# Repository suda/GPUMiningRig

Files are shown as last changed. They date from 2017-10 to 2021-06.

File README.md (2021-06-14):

# 6 GPU Mining Rig

<p align="center"><em>
	Read this in other languages: <a href="README.md">English</a>, <a href="README.pt-br.md">Português-Brasil</a>
</em></p>

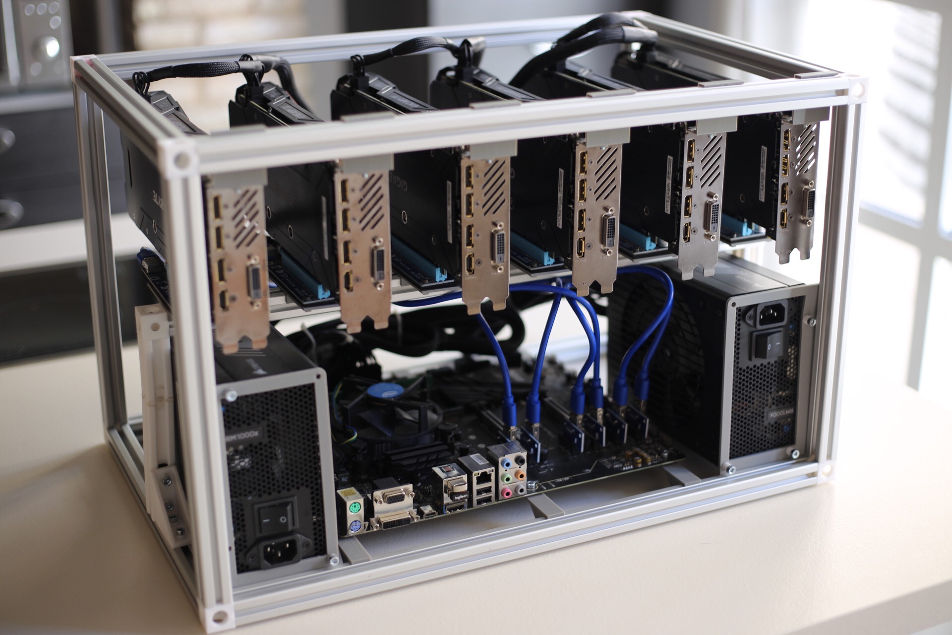
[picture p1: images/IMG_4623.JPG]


## General info

* Dimensions: 540x340x340mm
* Support for two PSUs
* Stackable
* Build cost: ~€60

### 💰 Donations

If you successfully build one I would appreciate some kickback ☺️

* **BTC:** `1K7Uc9MDzokCGEsUxrQQXn59VQ1Q9AWGvZ`
* **BCH:** `1BHM8oACVN6F4xksXAAP3nR9EoAkfd8sGF`
* **ETH:** `0x8CcA7589d8061ad4D3D913412d1EAD71cbEae081`
* **LTC:** `LRJ4Evzmyynp8Uswiy7e2uWhPKBNiSHroq`

## Parts, materials and tools

### Metal
* 5x 2020 500mm profiles
* 8x 2020 300mm profiles
* 2x 2020 150mm profiles
* 16x M3 8mm screws
* 40x M4 8mm screws
* 8x PC case 4mm screws
* 40x M4 nuts
* 28x M6 16mm screws (Make sure to get flat, countersunk screwheads)
* Zip ties

### 3D Printed

* 6x [GPU Bracket Rail](parts/GPUBracketRail.stl)
* 6x [Raiser Rail](parts/RaiserRail.stl)
* [PSU Frame Left](parts/PSUFrameLeft.stl)
* [PSU Frame Right](parts/PSUFrameRight.stl)
* [62mm Mobo Bracket Rail](parts/MoboBracketRail62mm.stl)
* 2x [40mm Mobo Bracket Rail](parts/MoboBracketRail40mm.stl)
* 3x [33mm Mobo Bracket Rail](parts/MoboBracketRail33mm.stl)
* 4x [Right Angle Bracket](parts_others/90_bracket.stl)
* 10x [2020 Corner Connector](parts_others/2020_connect_v2.stl)
* 40x [T Slot nut](parts_others/t_slot_nut_m4.stl)

## Optional
* 4x [Feet_v1](parts/Feet_v1.stl)
* 4x [Rail-Snapper-Insert__MotherBoardv1](parts/Rail-Snapper-Insert__MotherBoardv1.stl)
* 	These can be used to snap the motherboard brackets into place, so you won't need the screws.

### Tools

* Drill
* M6 screw tap
* 3D Printer

## Assembly

**Note:** Any dimensions are measured on the inner parts of the frame.

#### 1. Thread all the profiles
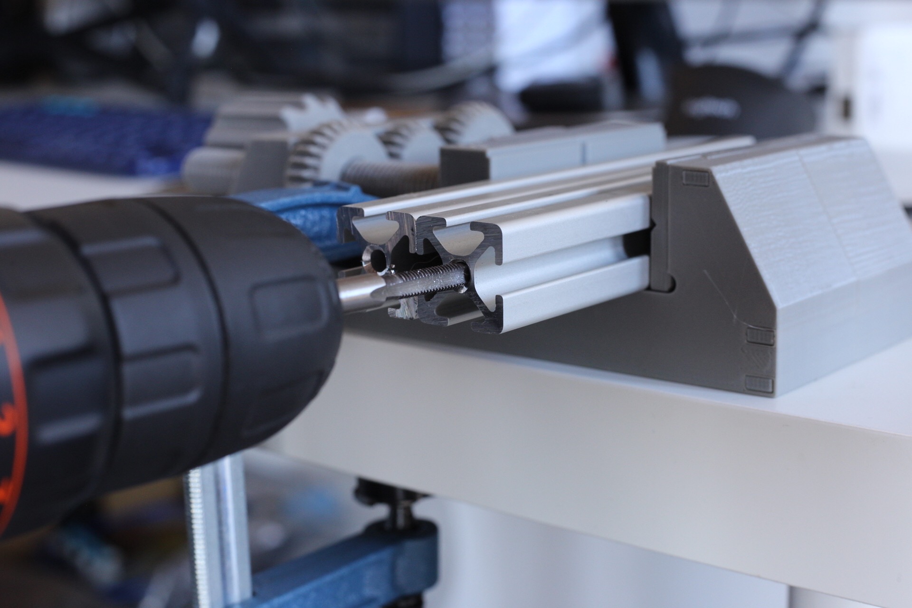
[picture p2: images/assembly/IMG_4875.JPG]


#### 2. Put M4 nuts into all printed T Slot nuts
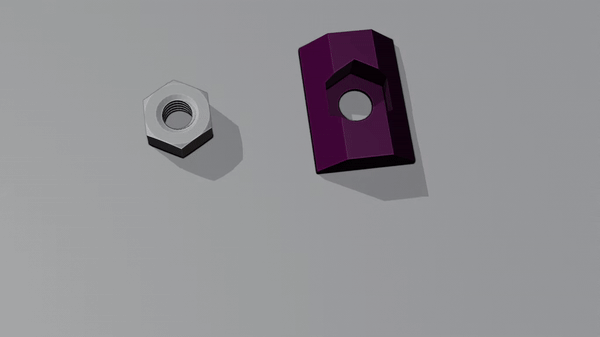
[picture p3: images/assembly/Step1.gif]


#### 3. Place the T Slot nuts in the following profiles:
	* 2x 6 nuts in 500mm
	* 7 nuts in 500mm
	* 3 nuts in 400mm
	* 4x 2 nuts in 300mm

#### 4. Screw the frame together using the M6 screws, 300mm+500mm profiles and the 2020 Corner Connectors

#### 5. Screw the PSU frames to both power supplies
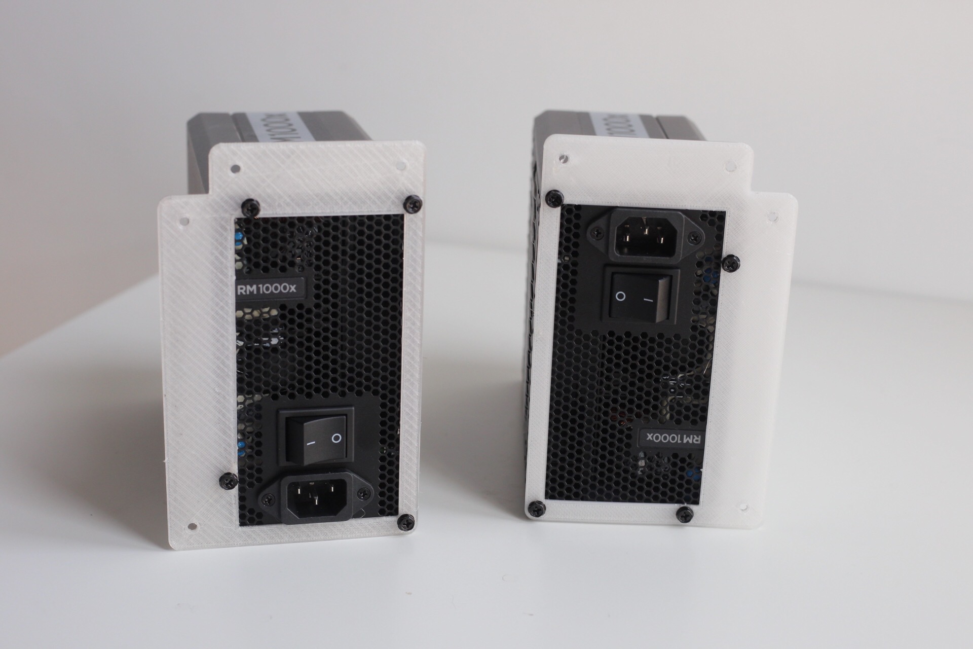
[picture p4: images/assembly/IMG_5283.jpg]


#### 6. Screw the PSU support Right Angle Brackets
**Note:** ~116mm from the back.
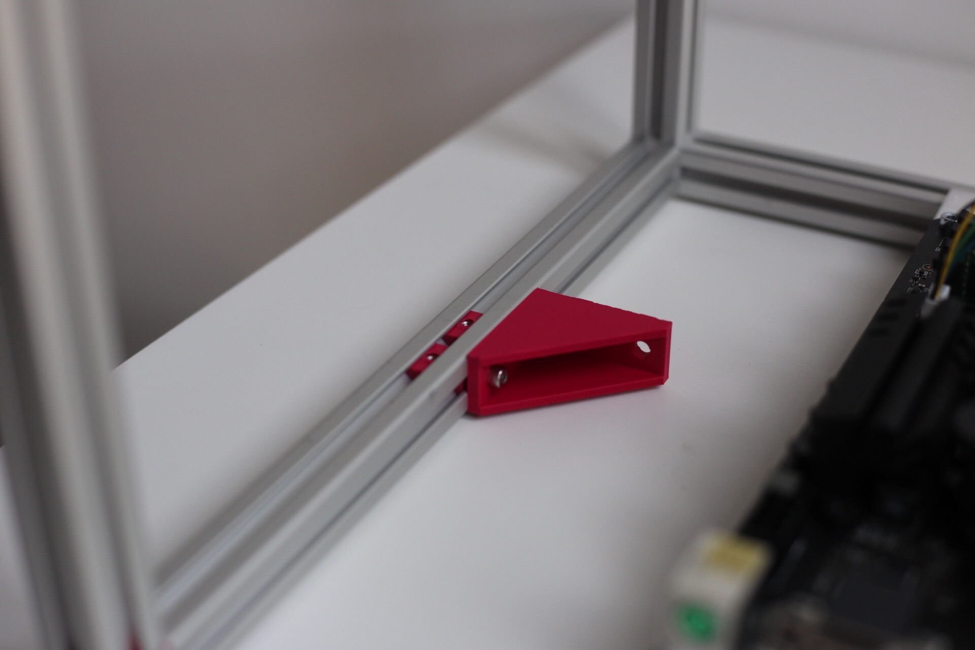
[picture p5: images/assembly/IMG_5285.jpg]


#### 7. Screw the MOBO standoffs and MOBO
**Note:** Leave ~100mm on both sides.
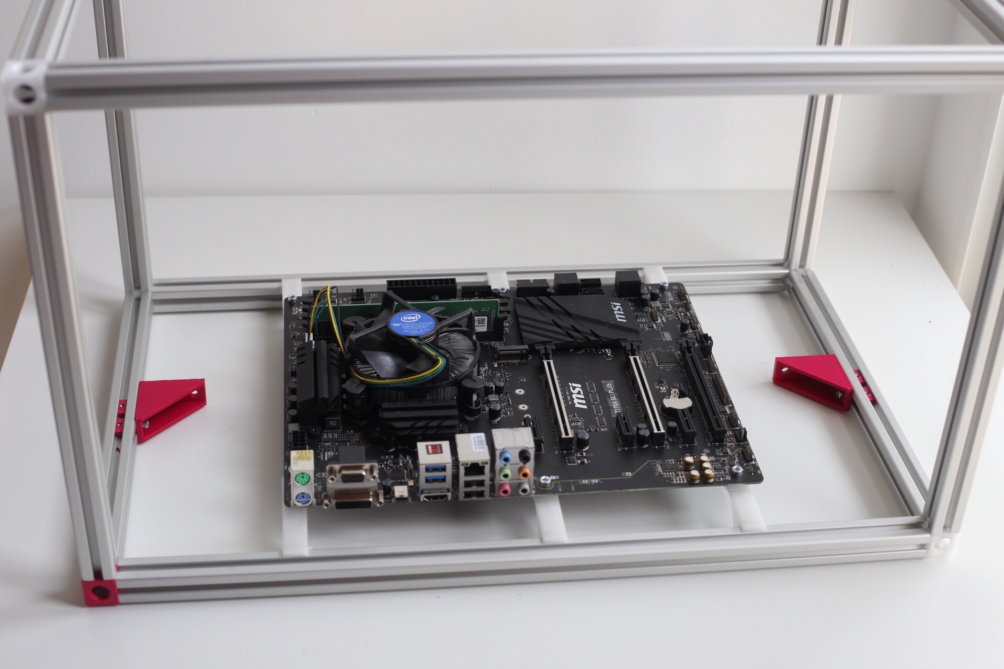
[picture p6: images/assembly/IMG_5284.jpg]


#### 8. Screw the PSUs to the main frame
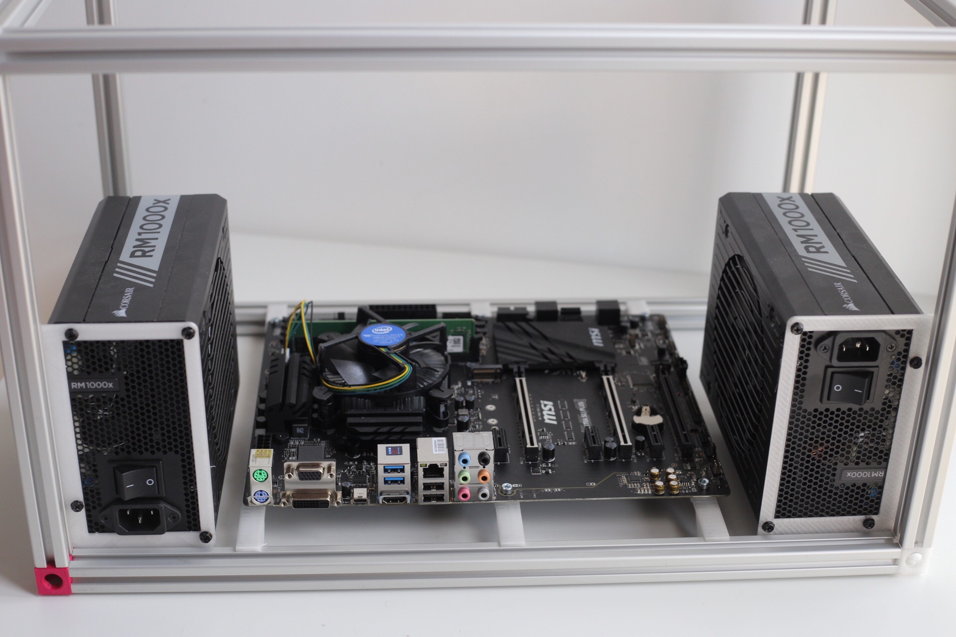
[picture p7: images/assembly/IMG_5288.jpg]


#### 9. Screw the raiser beam using the M6 screws, 150mm+500mm profiles and the two 2020 Corner Connectors to the frame using Right Angle Brackets
**Note:** 100mm from the front.
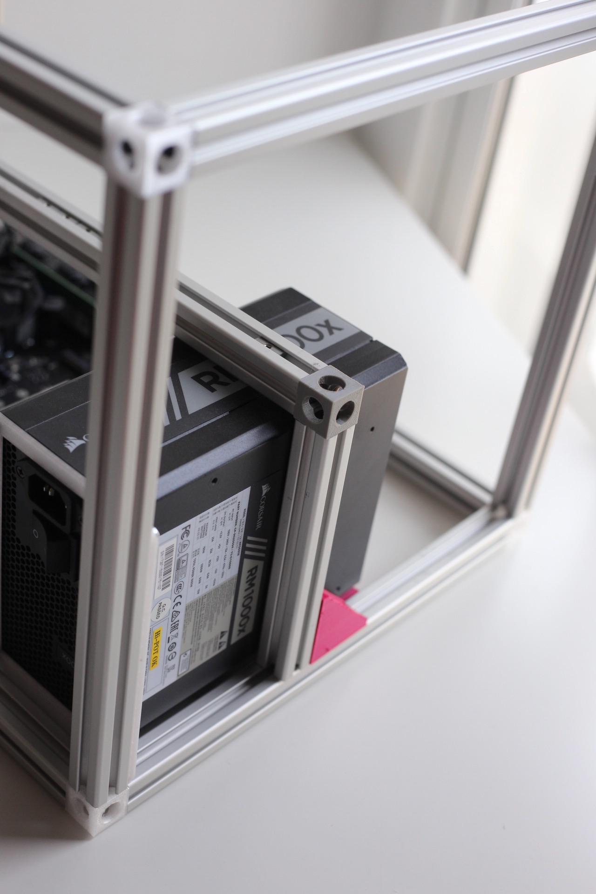
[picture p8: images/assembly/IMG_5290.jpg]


#### 10. Screw the Raiser Rails to the beam using M4 screws
**Note:** Place the first one by the left edge and then space other ones 44mm apart.
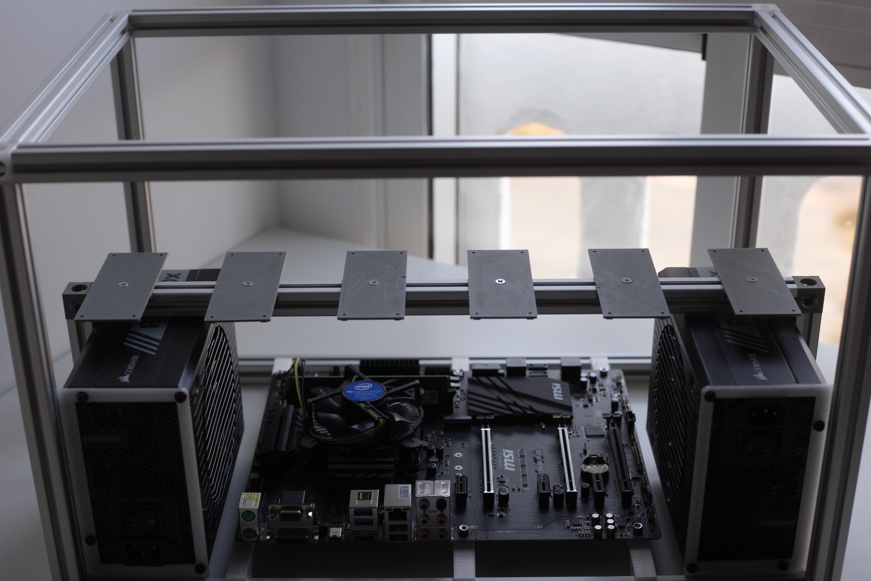
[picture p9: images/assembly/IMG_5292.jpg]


#### 11. Screw the GPU Bracket Rails to the upper part of the frame
**Note:** Place the first one by the right edge and then space other ones 55mm apart.
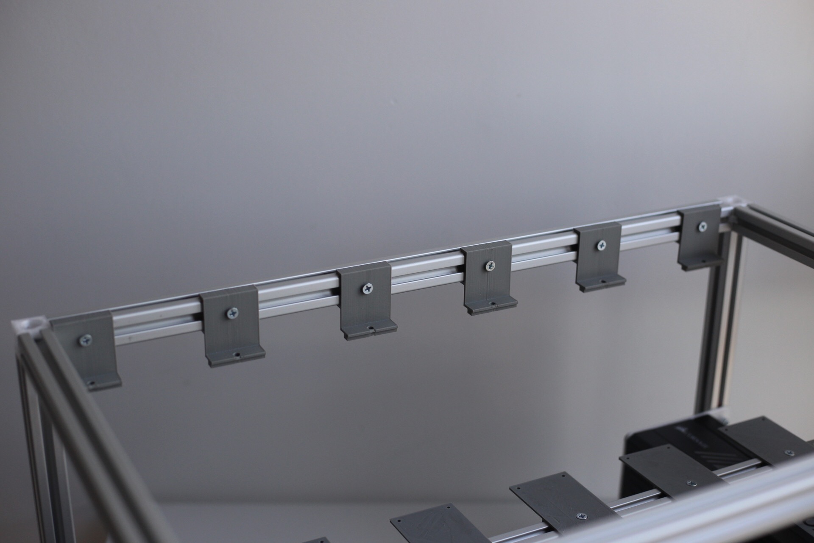
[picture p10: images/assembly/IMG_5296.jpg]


#### 12. Screw the raisers to the Raiser Rails with M3 screws
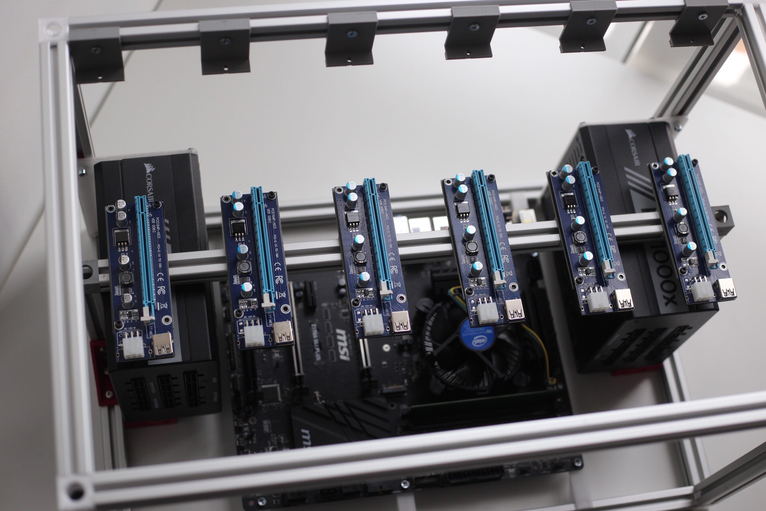
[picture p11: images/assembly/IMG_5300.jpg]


#### 13. Wire up the raiser data cables
**Note:** Don't tie the cables yet, that's the last step.

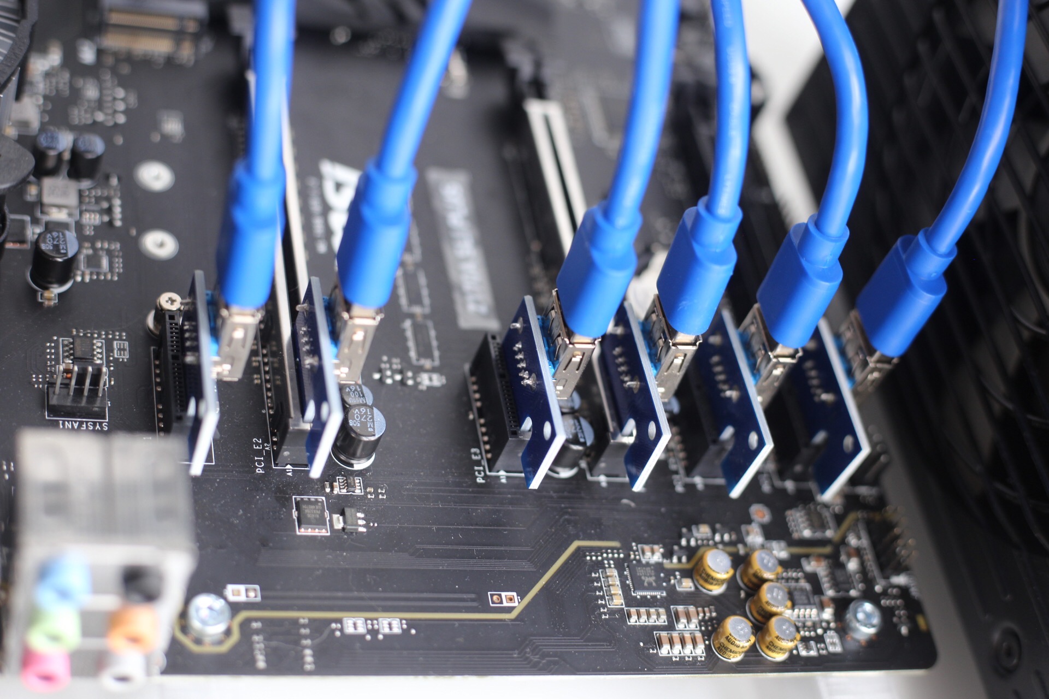
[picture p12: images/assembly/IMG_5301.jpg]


#### 14. Wire up the raiser and MOBO power cables
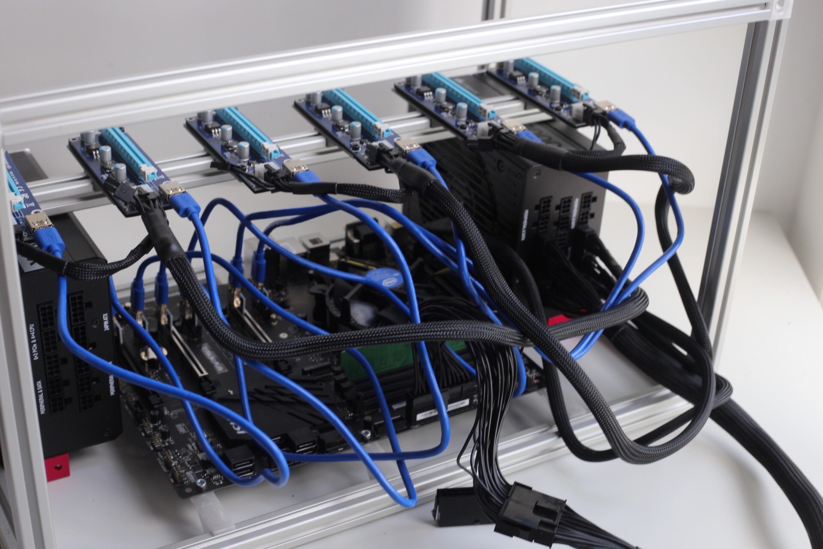
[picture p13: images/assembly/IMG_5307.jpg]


#### 15. Place all the GPUs and screw them to the GPU Bracket Rails

#### 16. Wire up GPU power cables

#### 17. Boot up and check if everything works correctly

#### 18. Use zip ties to clean up the cables

I recommend using [ethOS](http://ethosdistro.com) to manage your rigs. The setup very easy and fast saving a ton of work when configuring / managing more GPUs.

## 3rd Party Copyrights
Components in `parts_others` directory have been designed by following people:
* [2020 Corner Connector](https://www.thingiverse.com/thing:1100779) by [woodywong](https://www.thingiverse.com/woodywong/about)
* [Right Angle Bracket](https://www.thingiverse.com/thing:1810199) by [DCGTek](https://www.thingiverse.com/dcgtek/about)
* [T Slot nut](https://www.thingiverse.com/thing:1573410) by [Tomasz Mankiewicz](https://www.thingiverse.com/tomaq/about)

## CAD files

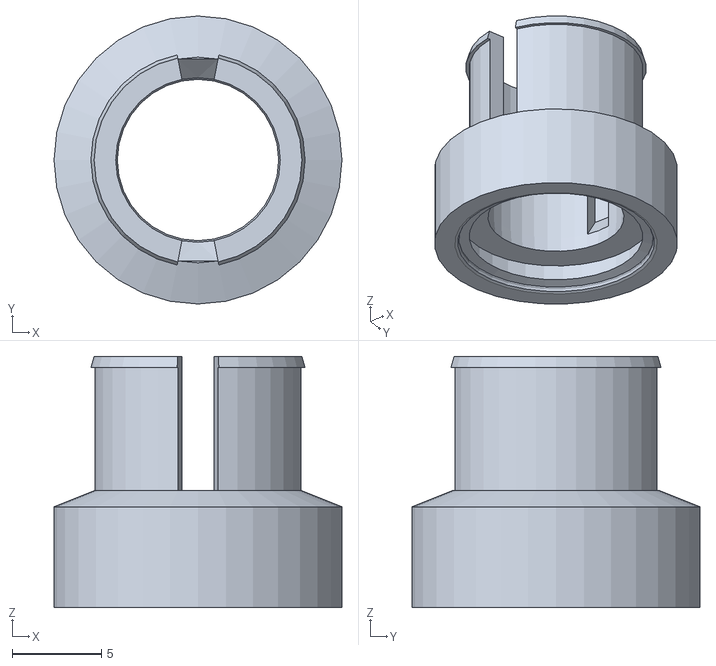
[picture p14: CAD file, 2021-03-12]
parts/Feet_v1.stl
16.2 x 16.2 x 14.1

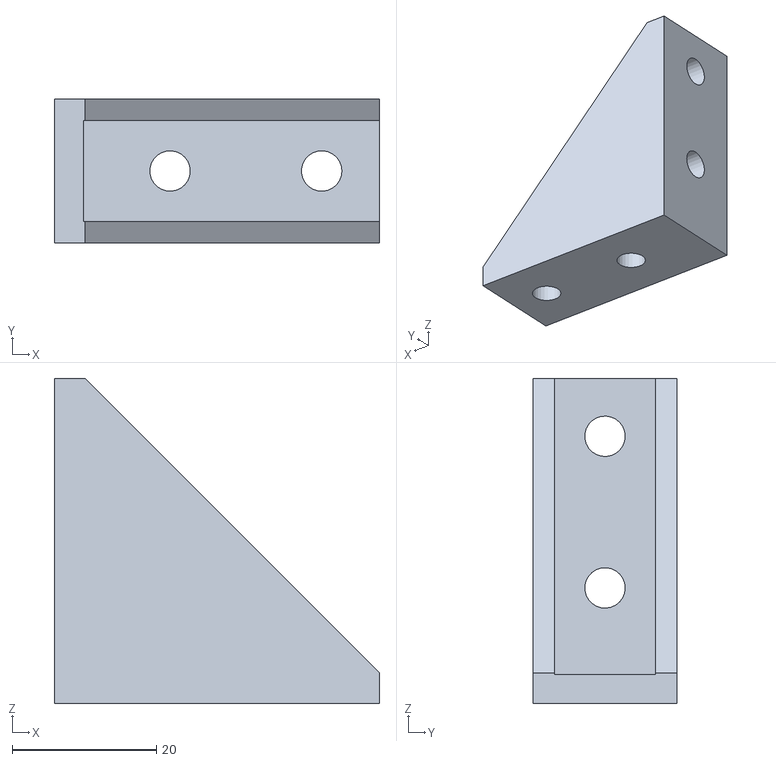
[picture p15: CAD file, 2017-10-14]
parts_others/90_bracket.stl
45.0 x 20.0 x 45.0

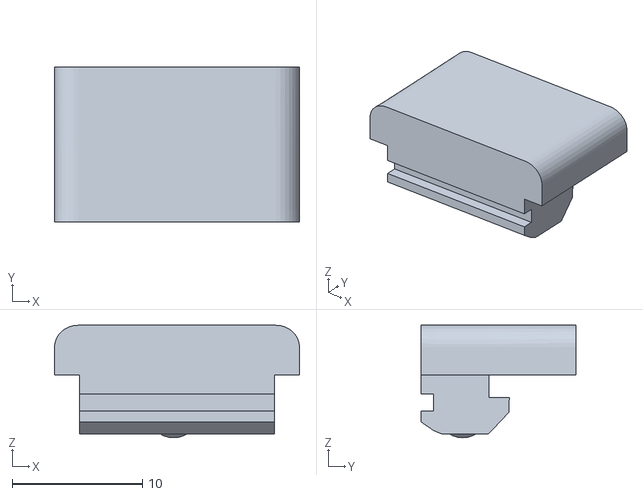
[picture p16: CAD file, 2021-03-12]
parts/Rail-Snapper-Insert__MotherBoardv1.stl
18.8 x 11.9 x 8.64

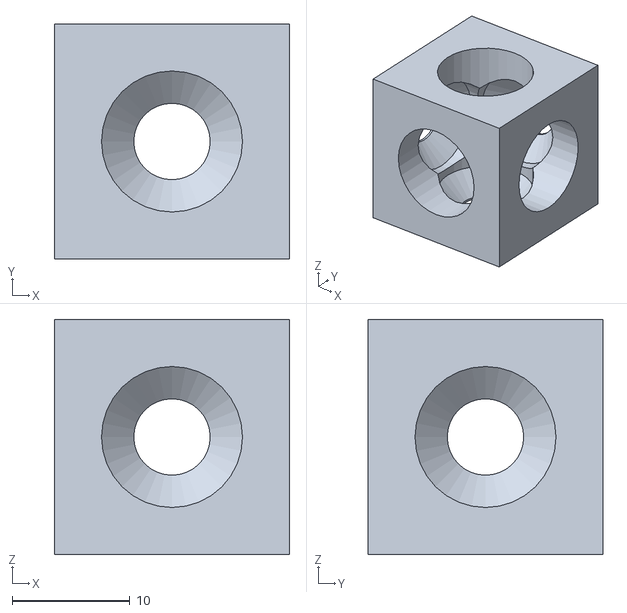
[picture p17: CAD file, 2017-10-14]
parts_others/2020_connect_v2.stl
20.0 x 20.0 x 20.0

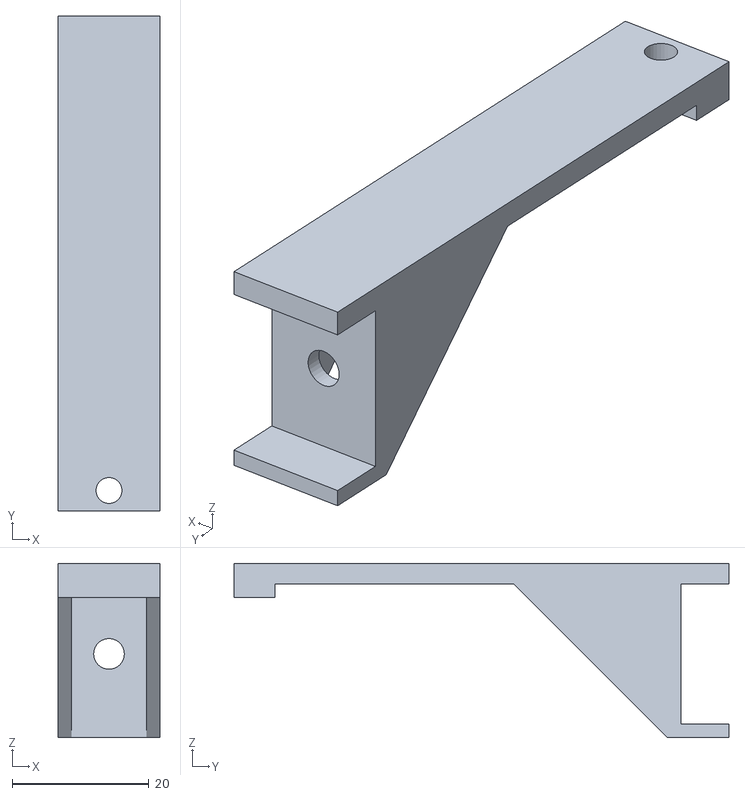
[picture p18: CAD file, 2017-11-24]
parts/MoboBracketRail62mm.stl
15.0 x 72.5 x 25.5

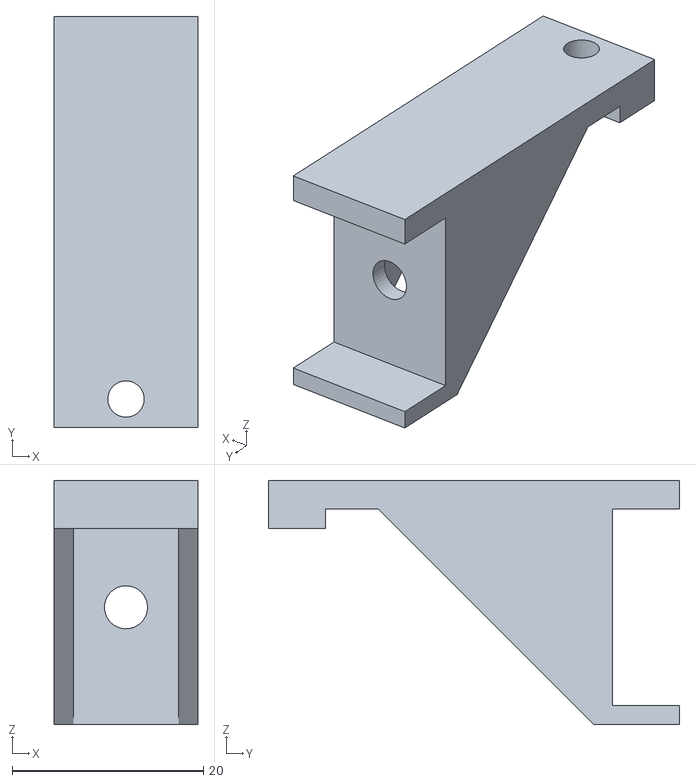
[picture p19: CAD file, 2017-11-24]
parts/MoboBracketRail33mm.stl
15.0 x 43.0 x 25.5

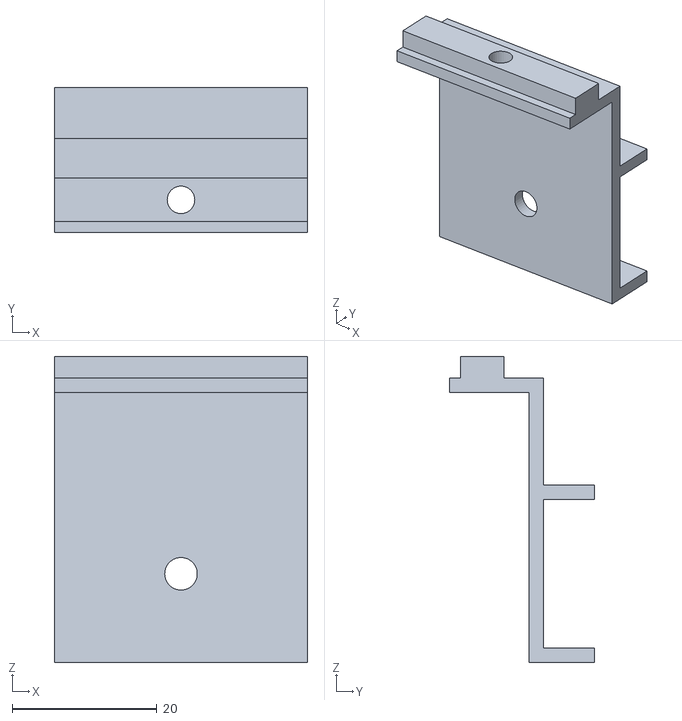
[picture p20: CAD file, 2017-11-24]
parts/GPUBracketRail.stl
35.0 x 20.0 x 42.2

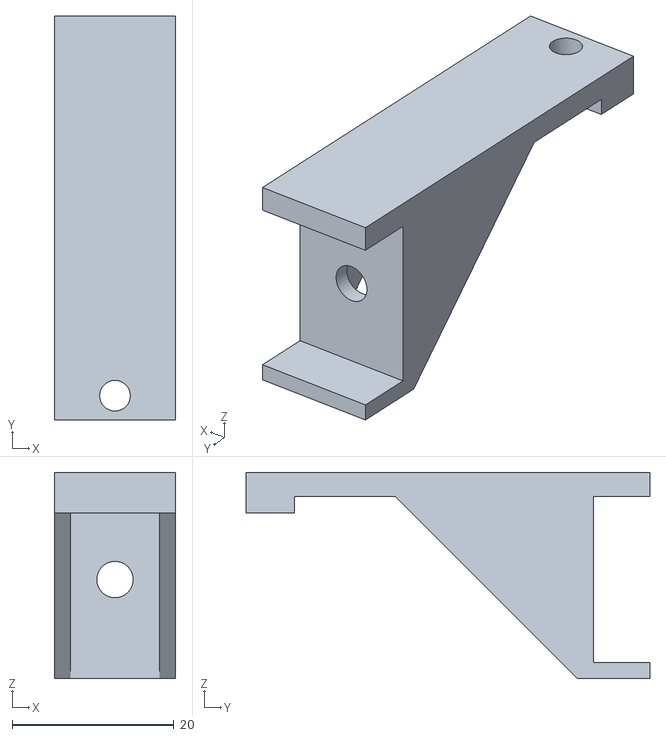
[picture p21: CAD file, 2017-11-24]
parts/MoboBracketRail40mm.stl
15.0 x 50.0 x 25.5

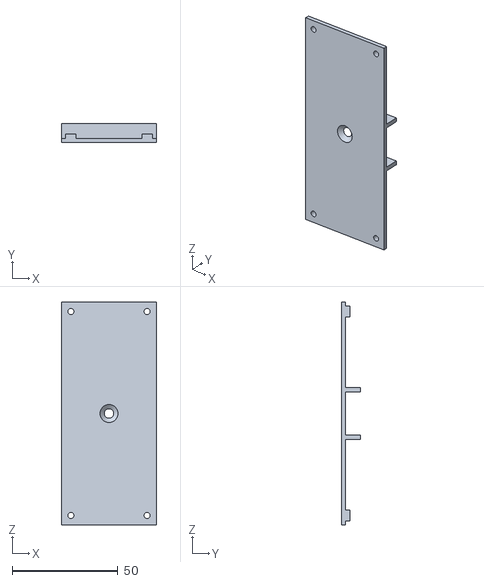
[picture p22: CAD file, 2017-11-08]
parts/RaiserRail.stl
45.0 x 9.00 x 105.5

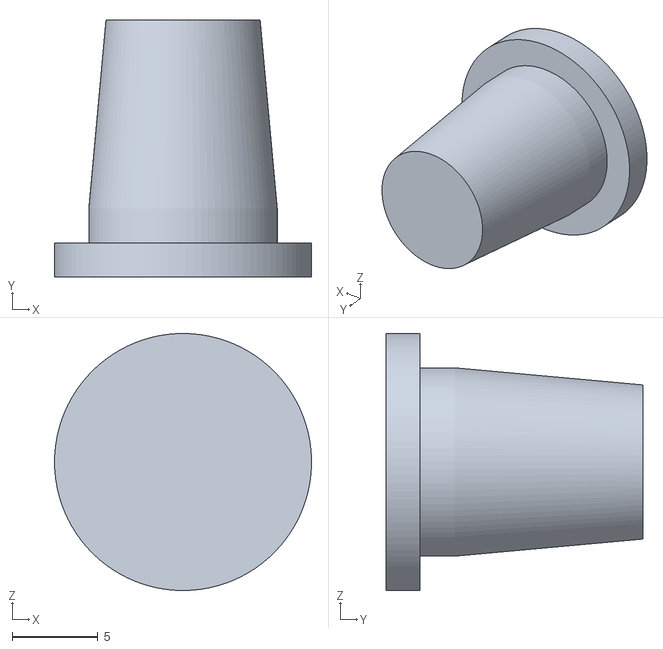
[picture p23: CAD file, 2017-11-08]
parts/Standoff.stl
15.0 x 15.0 x 15.0

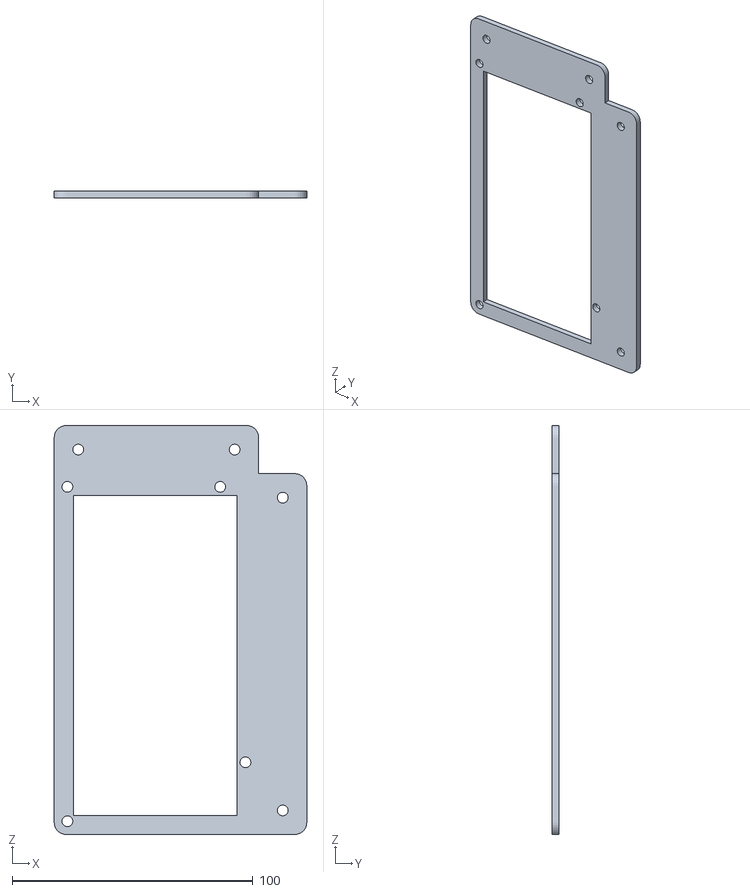
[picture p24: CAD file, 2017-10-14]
parts/PSUFrameLeft.stl
105.0 x 3.00 x 170.0

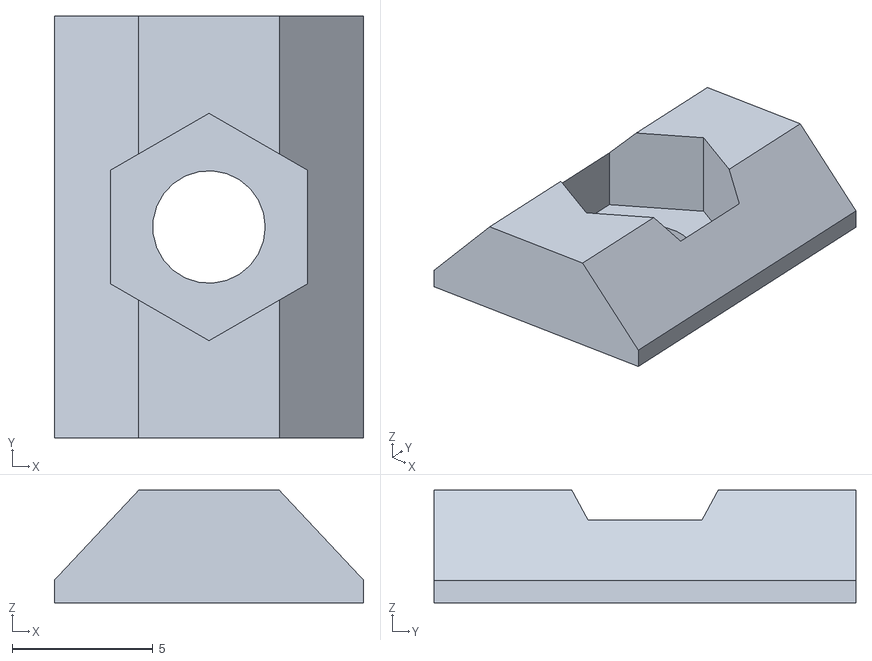
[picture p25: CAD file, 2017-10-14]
parts_others/t_slot_nut_m4.stl
11.0 x 15.0 x 4.00

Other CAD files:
parts/PSUFrameRight.stl

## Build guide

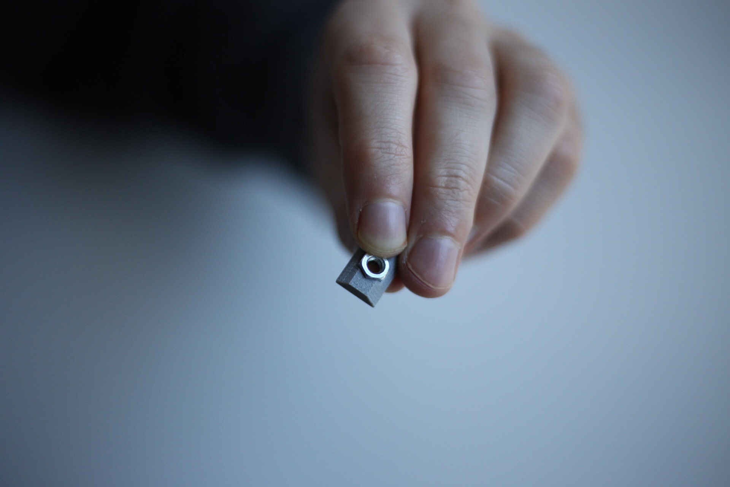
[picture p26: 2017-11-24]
images/assembly/IMG_4871.JPG

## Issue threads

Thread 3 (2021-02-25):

Powersupply brackets are not optimized

Cairo555, 2021-02-25:
I think these brackets are not 100% compliant with ATX standards. They don't fit on one of my old PSU's.

Antec 500Watt PSU.

The holes don't line up perfectly and I can't get the screw in on one of the brackets, because the tension is to high on the part.

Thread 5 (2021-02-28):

Where are the M3's being used?

emsilva, 2021-02-28:
Sorry, not clear to me. Where are you using the M3's? And any reason to not use a nut?

Cairo555, 2021-03-04:
I made one of these builds with some mods, and you are right the instructions are not really clear. I made a branch of this project. Maybe that helps a bit. But the M3's are being used for things like the GPU risers, see attached image.
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

Cairo555, 2021-03-04:
> Sorry, not clear to me. Where are you using the M3's? And any reason to not use a nut?

@emsilva
PS. I'm also working on a clamp+lock system, so you need less screws.

In the attached picture, you see two parts. The Red part, just clicks in the X-frame and can be removed by pushing the pin in, so you can take it out straight, to prevent it from sliding in the X rail, you use the yellow part, to lock it in place. Prototype works fine. At A, you see the yellow lock that attaches to the red clip and B will be hold in place by the rail. It unlock by sliding out the yellow lock.
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

emsilva, 2021-03-04:
Thats great, thanks mate. I like your approach with the clamping system!

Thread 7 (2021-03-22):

Nut size

LeonSpors, 2021-03-22:
There is no information about the used nut size of the profiles. Based on the used M4 nuts I assume that profiles are 2020 nut 4. Am I right? If yes, is this build is easily upgradable to nut 5? In my country I cannot find 2020 nut 4.

Cairo555, 2021-03-24:
Used size is 4. I don't think 5 will fit in the 2020 profile. Also if you change the nuts to 5. You will have to modify the stl for the little bits that slide into the rail.

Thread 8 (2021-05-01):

Questions

Miko958, 2021-05-01:
1. Do you use two different types of M4 8mm screws for the riser rails and the right angle brackets.
2. Do I need 24 M3 8mm screws for the risers since there are 24 holes for the risers.
3. What M size did you use for the PC case 4mm screws for the power supply.

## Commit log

2017-11-08 Updated files
    [GPUBracketRail.stl, PSUFrameLeft.stl, PSUFrameRight.stl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]
2017-11-24 Add more assembly photos
2017-11-24 Update the rails
    [GPUBracketRail.stl, MoboBracketRail33mm.stl, MoboBracketRail40mm.stl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]
2021-02-12 Update README.md
    There were some references to the profiles, which were missing a 0.
    So instead of referring to 500mm profile it referred to 50mm.
2021-02-18 Step 1, add nuts to the T-slot
2021-02-18 Instruction on how to add M4 nuts to T-Slot
2021-02-18 Step1
    Add 4mm nuts to t-slots
2021-02-24 Update README.md
    You don't need * 24x
    You need 28x screws, I also prefer M6 16mm, over M5 5mm screws, M6 is easier to work with.
    Also make sure you have the flat countersunk heads, Or they won't fit in the corner 2020's
2021-02-25 New standoffs for the rig itself.
    This standoff or feet, will be used on the corners of the rig, it actually snaps to the rig, but still allows for a bit of play.
    They STL has some errors, but they can be fixed in the slicer. Prints just fine. 0.2, 30% PLA.
    [Feet_v1.stl]
2021-02-25 Add the feet to print
2021-03-04 Update README.md
    changed a couple of M5 refrences to M6.
2021-03-06 Motherboard Snap-On
    This part can be used, to snap the motherboard brackets onto the X frame.
    Print at 0.2, it's a tight fit. If you want to remove them from the X frame, push a screwdriver underneath the part where the motherboard bracket goes in. So you can push it out.
    That's the only way I found to remove them from the frame :)
    [Rail-Snapper-Insert__MotherBoardv1.stl]
